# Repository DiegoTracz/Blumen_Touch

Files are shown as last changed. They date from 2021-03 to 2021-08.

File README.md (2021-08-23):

# Interruptor inteligente customizável
O projeto Blumen Touch, é uma solução IoT baseada no ESP8266 com o objetivo de popularizar sistemas de automação residencial de baixo custo.
<h2><b>Introdução</b></h2>
Blumen Touch é um interruptor wi-fi baseado no ESP8266 suportando até 3 botões e 3 relés de estado sólido que suportam 2A cada, 
permitindo controlar até 3 circuitos de iluminação independentes. O Blumen touch foi desenvolvido para ser instalado em caixinhas
4x2, padrão brasileiro, substituindo assim o interruptor padrão que esteja instalado. O controle pode ser feito via comando de voz, via web, smartphone ou manualmente pelos botões.
Além disso possui um interface customizável, onde é possivel colocar qualquer imagem ou foto e customizar como quiser.
<h2><b>Diagrama de fiação </b></h2>
<u1>
  <li> Ligação dos fio para os modelos B1, B2 e B3 </li>
  
  <li> Tutorial instalação:  https://youtu.be/j6668FpMcGA </li>
  <u1>
   <h2>

<h2><b>Bibliotecas necessárias</b></h2>

|  <b>Nome</b> |  <b>Link</b> |
|---|---|
| ArduinoJson  |<a href="https://github.com/bblanchon/ArduinoJson/">GIT</a>  | 
|  WebSockets | <a href="https://github.com/Links2004/arduinoWebSockets/">GIT</a>  |  
| Sirincpro  |  <a href="https://github.com/sinricpro/esp8266-esp32-sdk/">GIT</a> | 
| WifiManager  |<a href="https://github.com/tzapu/WiFiManager/">GIT</a> | 

<h2><b>Hardware</b></h2>
<u1>
  <li> Blumen Touch Placa 1, 2 e 3 teclas frente e trás</li>
  
  
  
  <u1>
   <h2><b>Suporte para placa</b></h2
     
 <u1>
  <li> Suporte (PLA) e espelho (acrilico) </li>
     

 <u1>
   <h2><b>Esquemáticos</b></h2>
     
<u1>
  <li> Esquematico frente </li>
  
  <li> Esquematico trás </li>
   
  
  <u1>
   
  <h2><b>GPIO's</b></h2>

|  <b>GPIO</b> |  <b>PINO</b> |
|---|---|
|16  | BOTÃO 1  | 
|  14 | BOTÃO 2  |  
| 12  |  BOTÃO 3|
| 05  |  RELÉ 1| 
| 04  |  RELÉ 2| 
| 02  |  RELÉ 3| 

  <h2><b>Software necessário</b></h2>
 <li><b>Sirinc Pro</b>: O Sirinc Pro é um serviço de nuvem para dispositivos inteligentes, onde de forma gratuita podemos hospedar até 3 dispositivos gratuitamente e a partir dele fazer o acionamento dos interruptores pelo aplicativo ou comando de voz.</li>
  <li> <b> Passo a passo configuração da placa utilizando a plataforma do Sinric Pro<b>: https://youtu.be/px-q5iuD3NI</li>

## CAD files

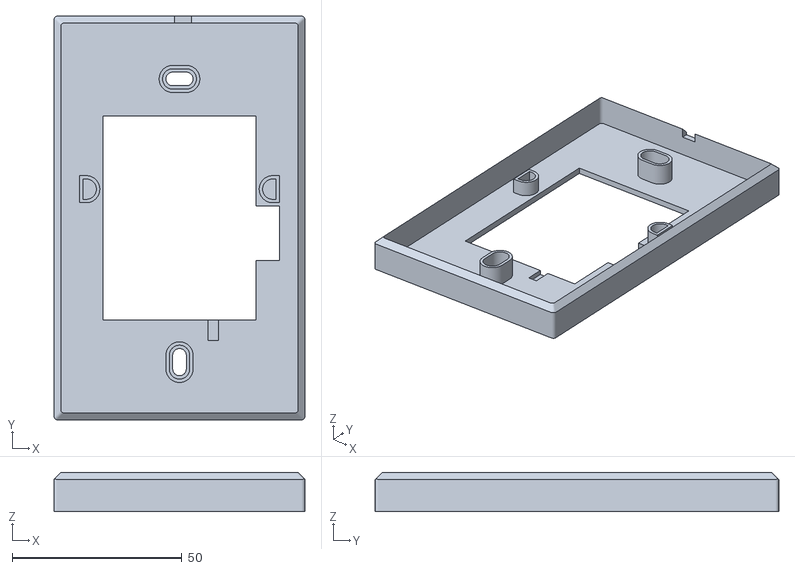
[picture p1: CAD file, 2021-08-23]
Impressão 3d/SuporteInterruptor.stl
74.0 x 119.0 x 11.6

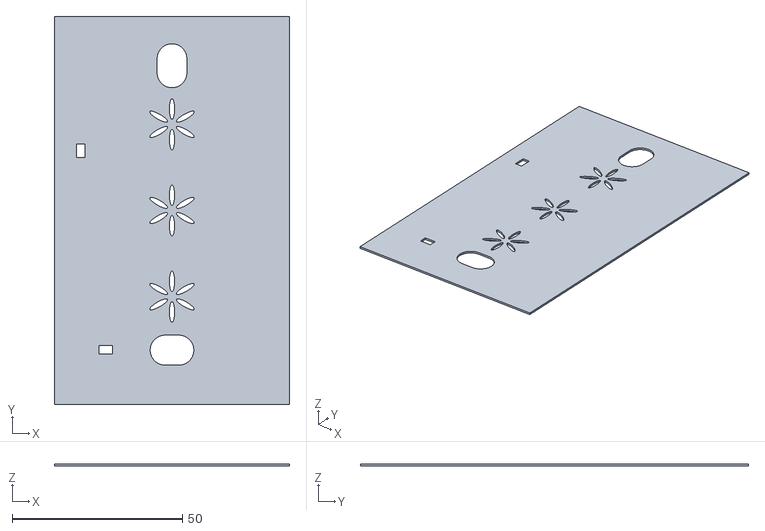
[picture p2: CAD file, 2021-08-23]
Impressão 3d/Proteção placa.stl
69.0 x 114.0 x 0.6

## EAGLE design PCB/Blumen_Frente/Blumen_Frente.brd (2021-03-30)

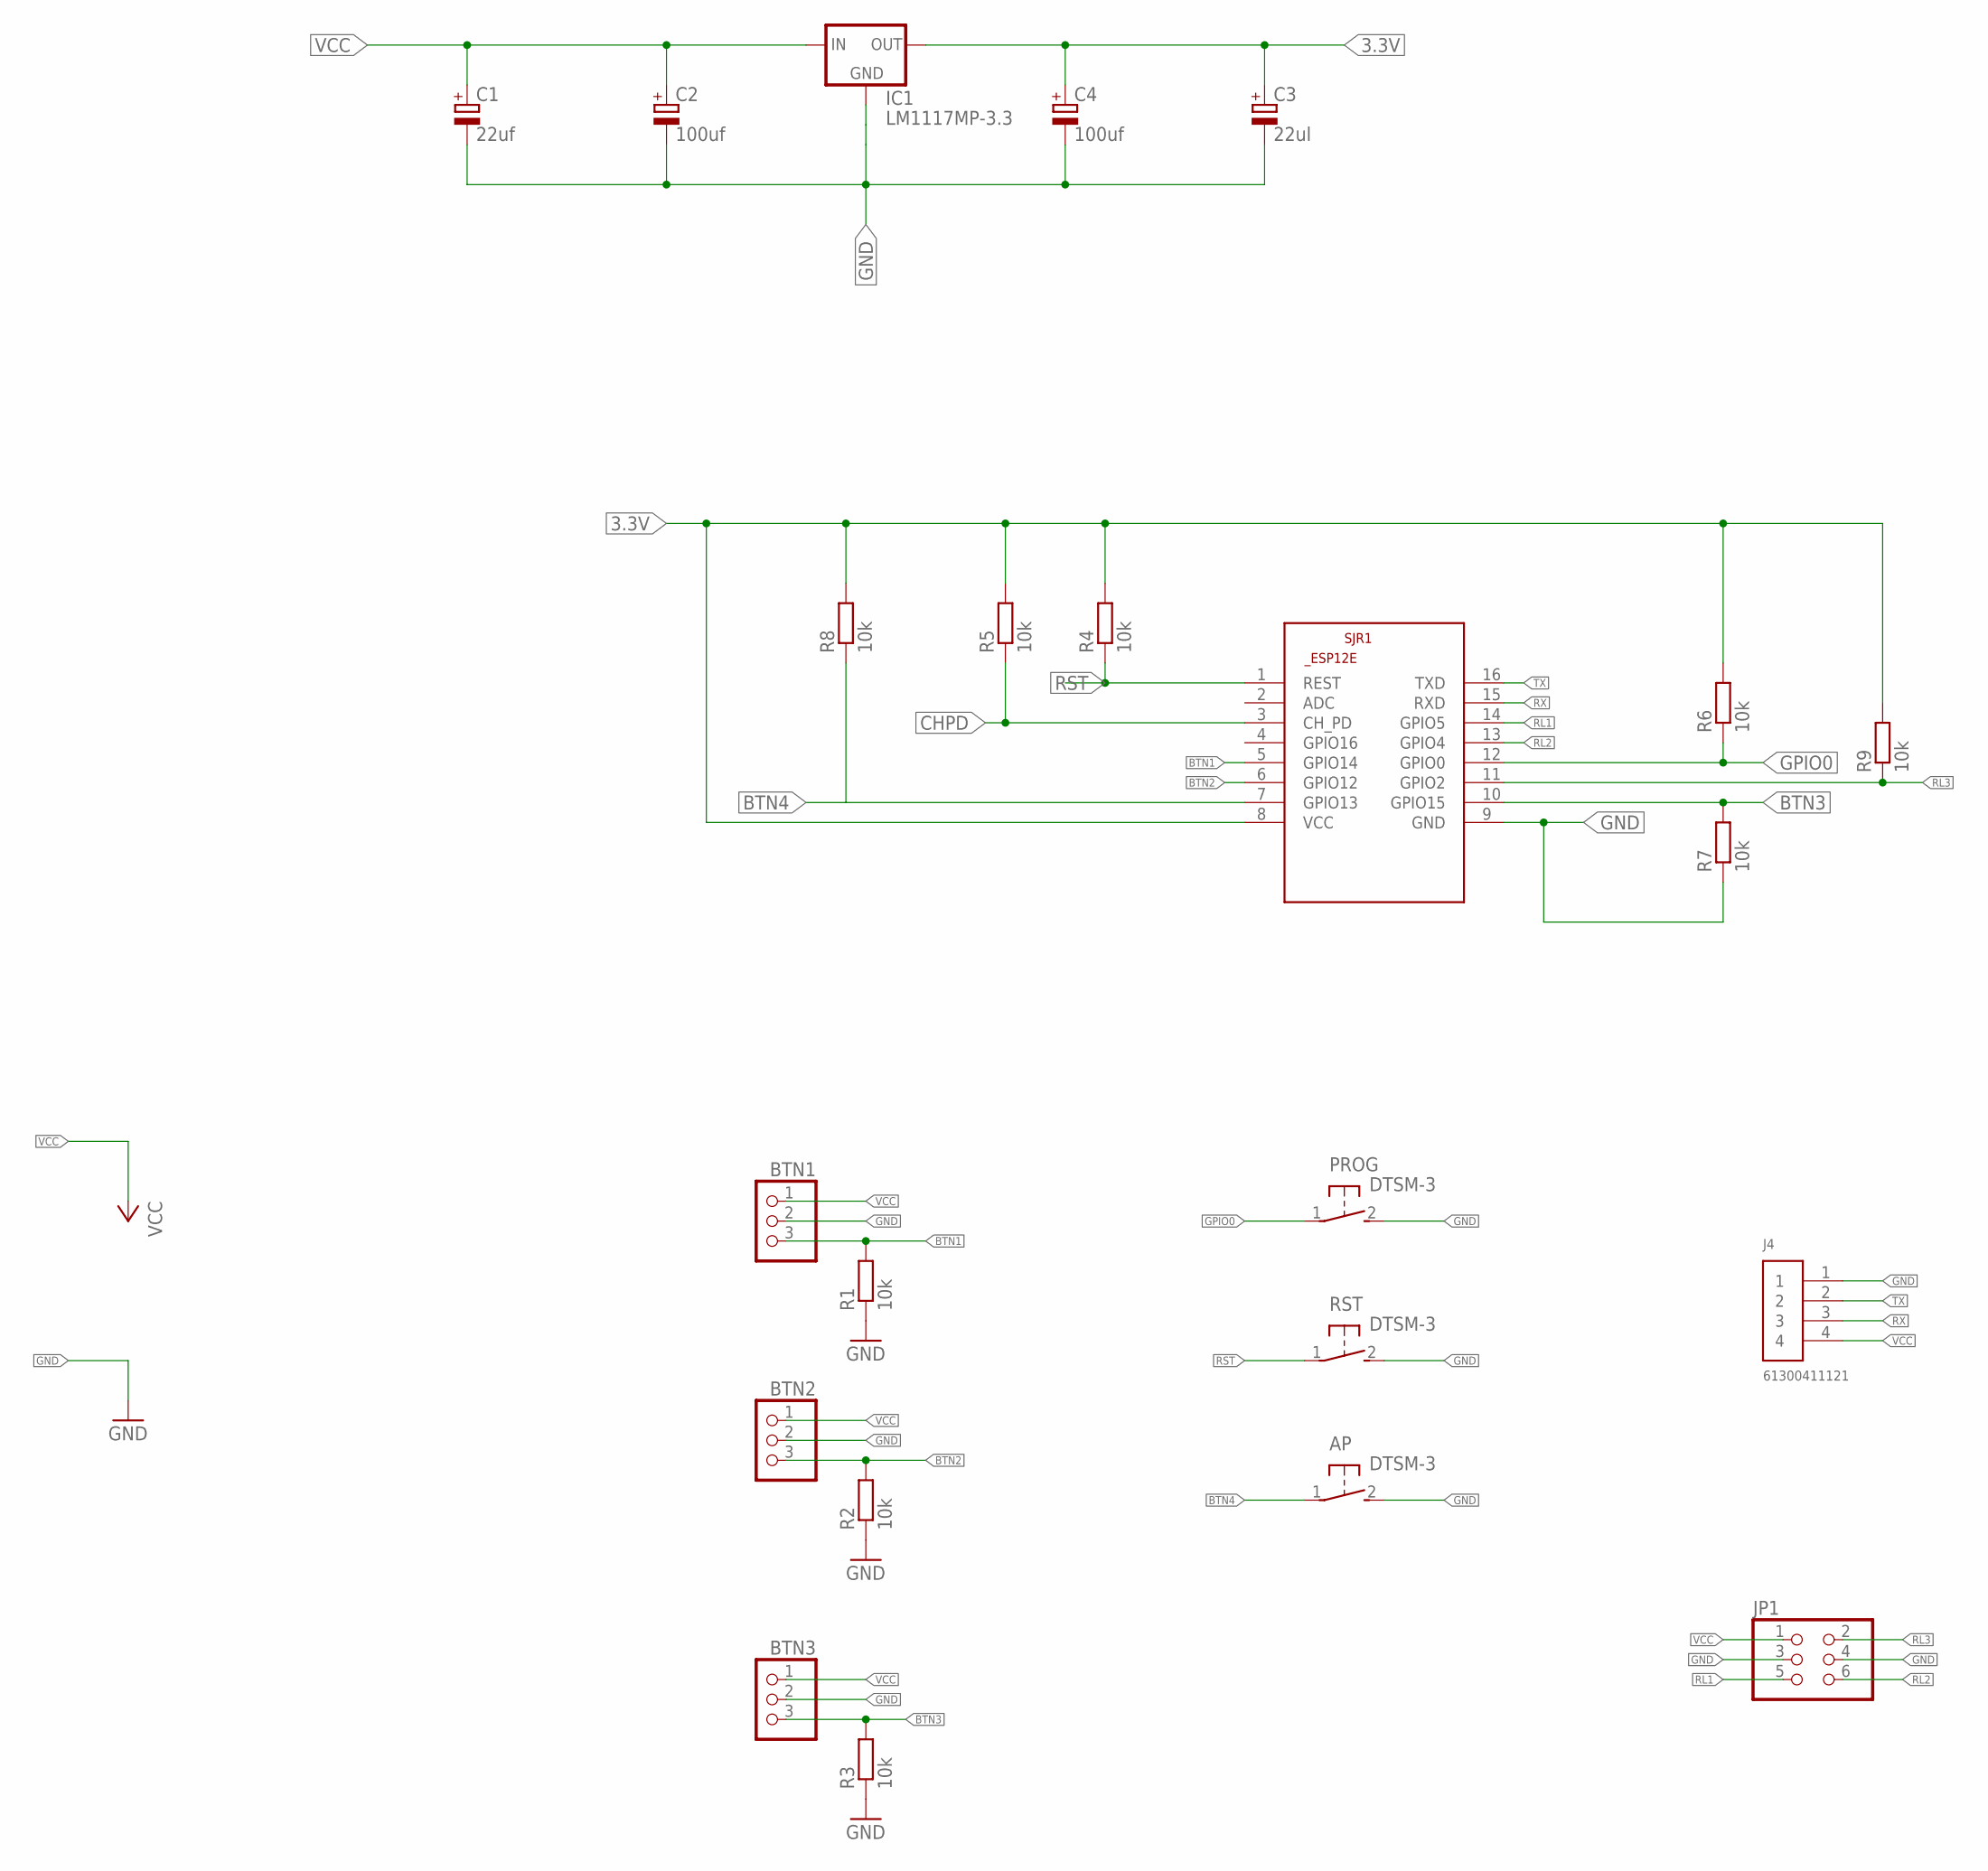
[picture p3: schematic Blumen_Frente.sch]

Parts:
AP: DTSM-3
BTN1, BTN2, BTN3: PINHD-1X3; 1X03
C1: 22uf; 153CLV-0505
C2, C4: 100uf; 153CLV-0605
C3: 22ul; 153CLV-0505
IC1: LM1117MP-3.3; SOT223
J4: 61300411121
JP1: PINHD-2X3; 2X03
PROG: DTSM-3
R1, R2, R3, R4, R5, R6, R7, R8, R9: 10k; R0805
RST: DTSM-3
SJR1: ESP8266-12EESP12E; ESP8266-ESP12E

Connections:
3.3V: C3.+, C4.+, IC1.2 (OUT), IC1.4 (OUT), R4.2, R5.2, R6.2, R8.2, R9.2, SJR1.8 (VCC)
BTN1: BTN1.3, R1.2, SJR1.5 (GPIO14)
BTN2: BTN2.3, R2.2, SJR1.6 (GPIO12)
BTN3: BTN3.3, R3.2, R7.2, SJR1.10 (GPIO15)
BTN4: AP.1, R8.1, SJR1.7 (GPIO13)
CHPD: R5.1, SJR1.3 (CH_PD)
GND: AP.2, BTN1.2, BTN2.2, BTN3.2, C1.-, C2.-, C3.-, C4.-, IC1.1 (GND), J4.1, JP1.3, JP1.4, PROG.2, R1.1, R2.1, R3.1, R7.1, RST.2, SJR1.9 (GND)
GPIO0: PROG.1, R6.1, SJR1.12 (GPIO0)
RL1: JP1.5, SJR1.14 (GPIO5)
RL2: JP1.6, SJR1.13 (GPIO4)
RL3: JP1.2, R9.1, SJR1.11 (GPIO2)
RST: R4.1, RST.1, SJR1.1 (REST)
RX: J4.3, SJR1.15 (RXD)
TX: J4.2, SJR1.16 (TXD)
VCC: BTN1.1, BTN2.1, BTN3.1, C1.+, C2.+, IC1.3 (IN), J4.4, JP1.1

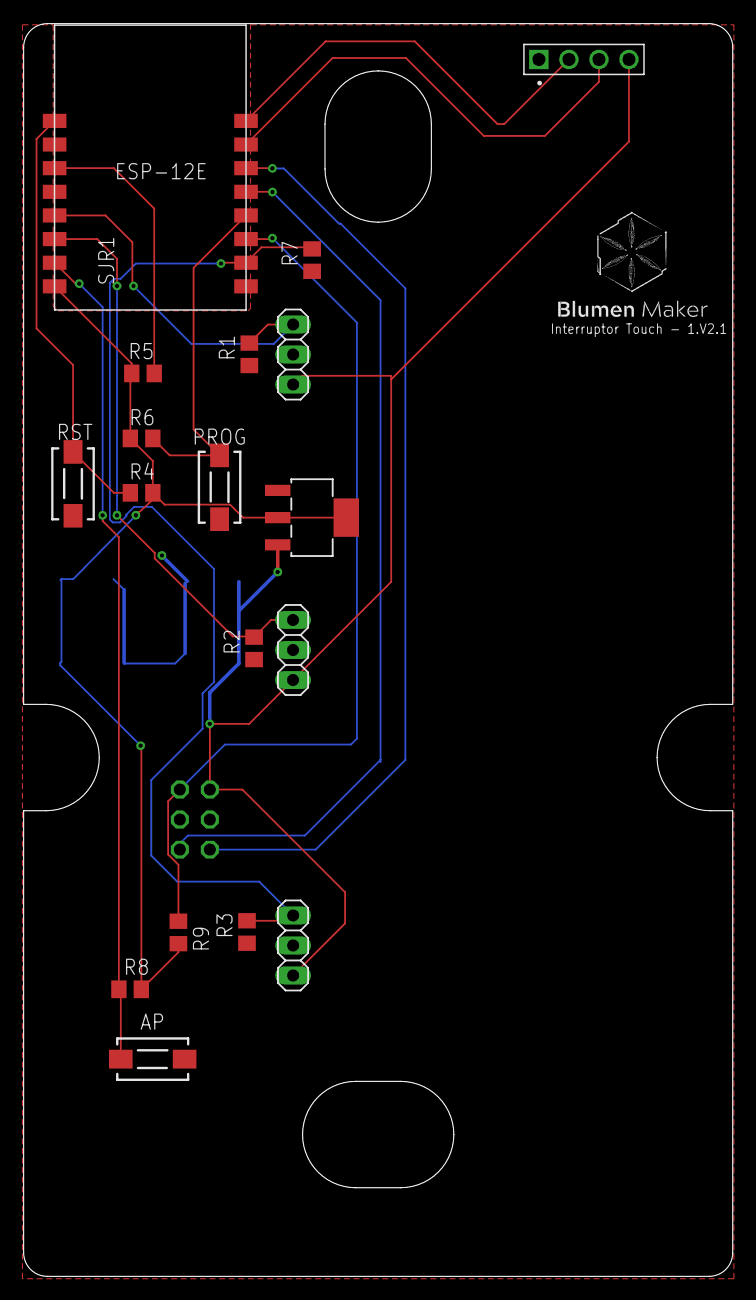
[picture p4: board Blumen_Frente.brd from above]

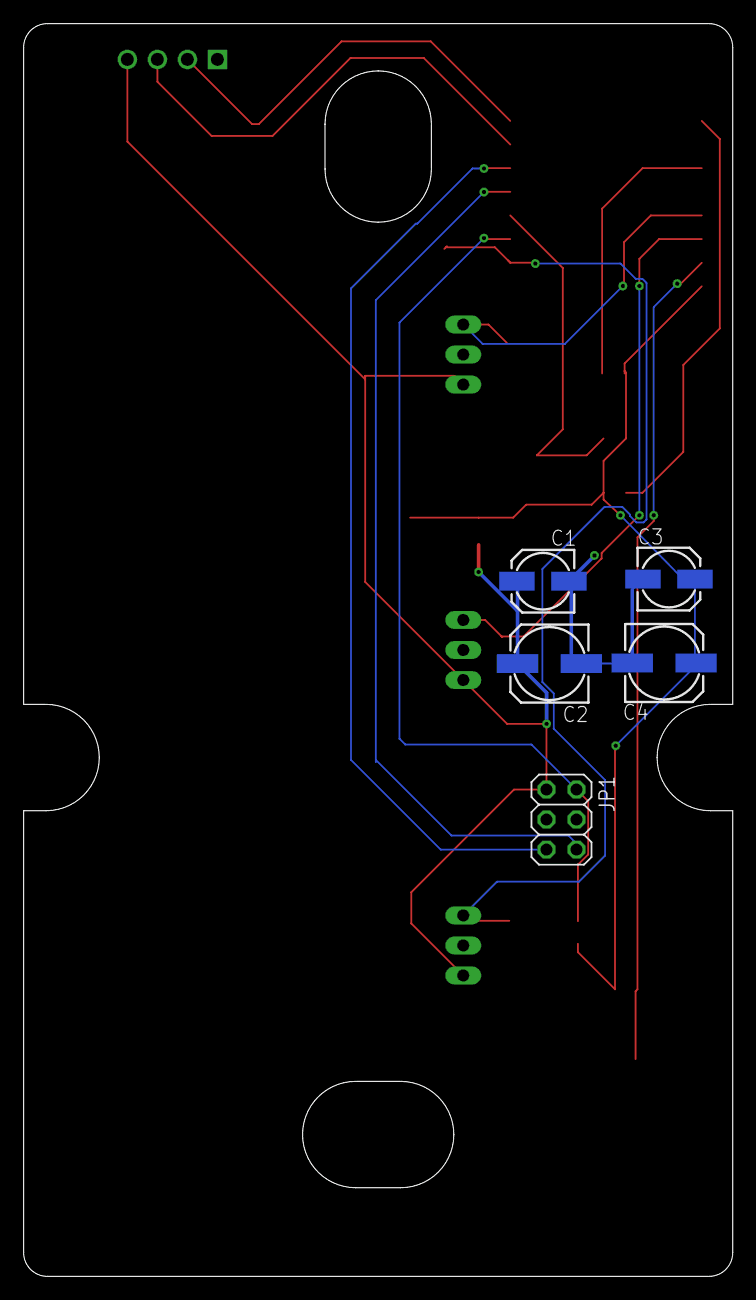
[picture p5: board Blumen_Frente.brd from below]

Board: 2 copper layers, 60.0 x 106.0 mm, 23 parts (5 on the bottom side), 15 nets.

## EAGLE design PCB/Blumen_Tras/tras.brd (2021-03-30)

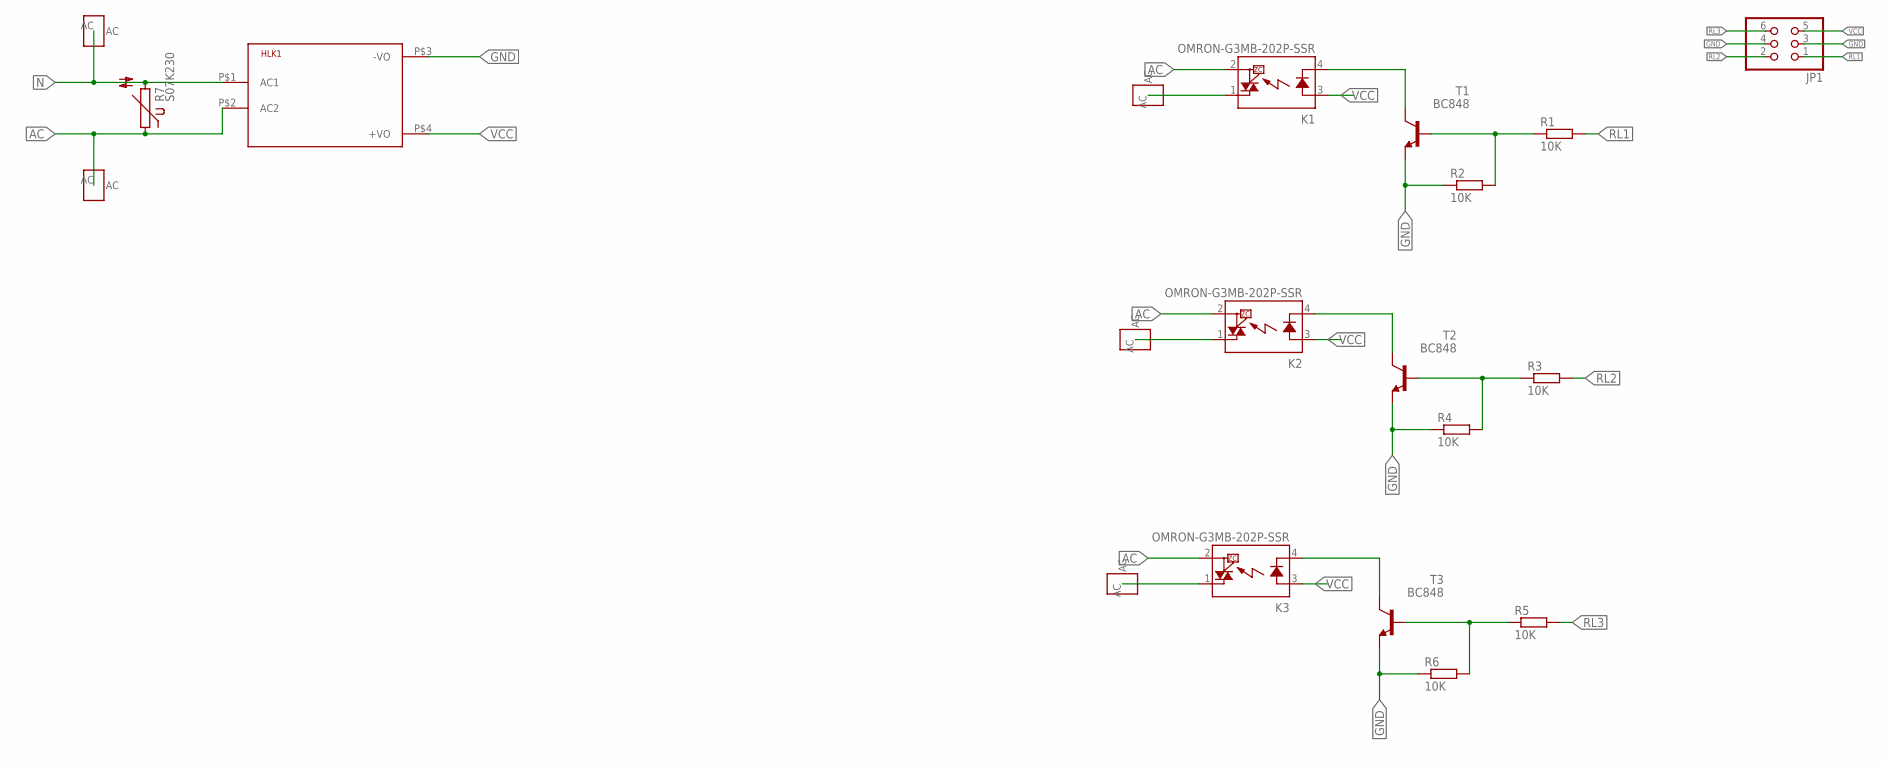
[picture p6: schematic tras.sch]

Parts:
AC: PAN_AC; PAD_AC
HLK1: HLK-PM013W; HLK-PM01
JP1: PINHD-2X3M; 2X03M
K1, K2, K3: OMRON-G3MB-202P-SSR
L1, L2, L3: PAN_AC; PAD_AC
N: PAN_AC; PAD_AC
R1, R2, R3, R4, R5, R6: 10K; R0805
R7: S07K230
T1, T2, T3: BC848; SOT23

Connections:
AC: AC.AC, HLK1.P$2 (AC2), K1.2 (DS2), K2.2 (DS2), K3.2 (DS2), R7.1
GND: HLK1.P$3 (-VO), JP1.3, JP1.4, R2.1, R4.1, R6.1, T1.2 (E), T2.2 (E), T3.2 (E)
L1: K1.1 (DS1), L1.AC
L2: K2.1 (DS1), L2.AC
L3: K3.1 (DS1), L3.AC
N: HLK1.P$1 (AC1), N.AC, R7.2
unnamed: K1.4 (K), T1.3 (C)
unnamed: R1.1, R2.2, T1.1 (B)
unnamed: K2.4 (K), T2.3 (C)
unnamed: R3.1, R4.2, T2.1 (B)
unnamed: K3.4 (K), T3.3 (C)
unnamed: R5.1, R6.2, T3.1 (B)
RL1: JP1.1, R1.2
RL2: JP1.2, R3.2
RL3: JP1.6, R5.2
VCC: HLK1.P$4 (+VO), JP1.5, K1.3 (A), K2.3 (A), K3.3 (A)

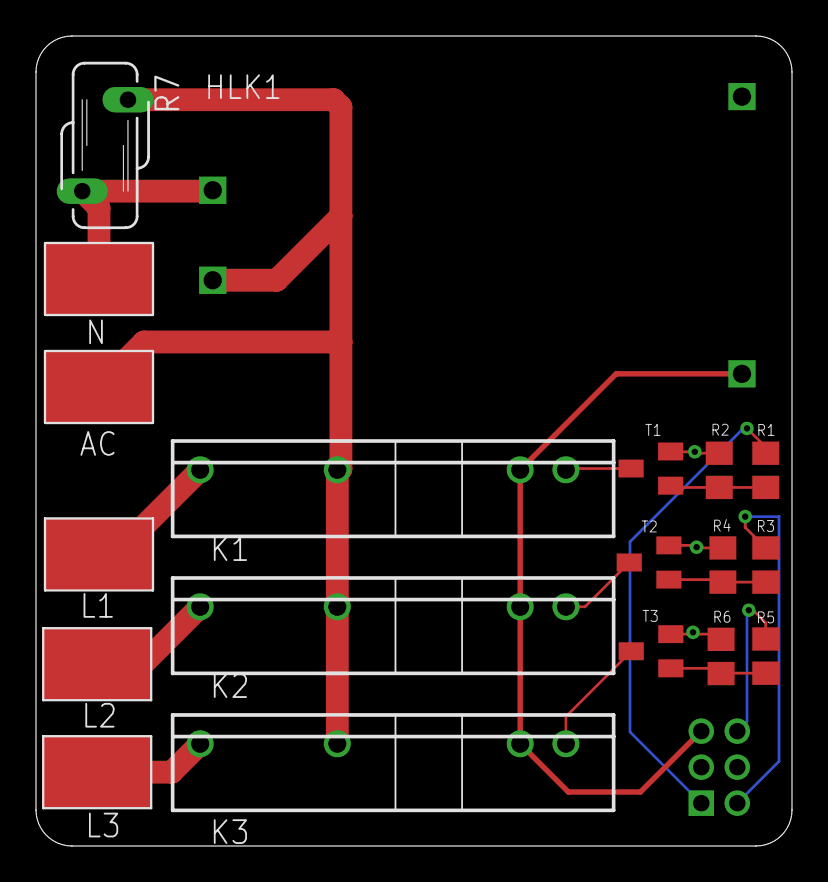
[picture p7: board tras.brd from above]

Board: 2 copper layers, 42.0 x 45.0 mm, 20 parts (1 on the bottom side), 16 nets.

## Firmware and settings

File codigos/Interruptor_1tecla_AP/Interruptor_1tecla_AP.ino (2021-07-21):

 /*
   ADVANCED example for: how to use up to N SinricPro Switch devices on one ESP module
                         to control N relays and N flipSwitches for manually control:
   - setup N SinricPro switch devices
   - setup N relays
   - setup N flipSwitches to control relays manually
     (flipSwitch can be a tactile button or a toggle switch and is setup in line #52)

   - handle request using just one callback to switch relay
   - handle flipSwitches to switch relays manually and send event to sinricPro server

   - SinricPro deviceId and PIN configuration for relays and buttins is done in std::map<String, deviceConfig_t> devices

   If you encounter any issues:
   - check the readme.md at https://github.com/sinricpro/esp8266-esp32-sdk/blob/master/README.md
   - ensure all dependent libraries are installed
     - see https://github.com/sinricpro/esp8266-esp32-sdk/blob/master/README.md#arduinoide
     - see https://github.com/sinricpro/esp8266-esp32-sdk/blob/master/README.md#dependencies
   - open serial monitor and check whats happening
   - check full user documentation at https://sinricpro.github.io/esp8266-esp32-sdk
   - visit https://github.com/sinricpro/esp8266-esp32-sdk/issues and check for existing issues or open a new one
*/

// Uncomment the following line to enable serial debug output
//#define ENABLE_DEBUG

#ifdef ENABLE_DEBUG
#define DEBUG_ESP_PORT Serial
#define NODEBUG_WEBSOCKETS
#define NDEBUG
#endif

#include <Arduino.h>
#ifdef ESP8266
#include <ESP8266WiFi.h>
#endif
#ifdef ESP32
#include <WiFi.h>
#endif

#include <WiFiManager.h>//https://github.com/tzapu/WiFiManager

#include "SinricPro.h"
#include "SinricProSwitch.h"

#include <map>

#include <DNSServer.h>
#include <ESP8266WebServer.h>

#define APP_KEY           "cole aqui o app_key"      // Should look like "de0bxxxx-1x3x-4x3x-ax2x-5dabxxxxxxxx"
#define APP_SECRET        "cole aqui o app_secret"  // Should look like "5f36xxxx-x3x7-4x3x-xexe-e86724a9xxxx-4c4axxxx-3x3x-x5xe-x9x3-333d65xxxxxx"

// comment the following line if you use a toggle switches instead of tactile buttons
#include <FS.h>
#define BAUD_RATE   9600

#define DEBOUNCE_TIME 250

#define AP_PIN  13

typedef struct {      // struct for the std::map below
  int relayPIN;
  int flipSwitchPIN;
} deviceConfig_t;


// this is the main configuration
// please put in your deviceId, the PIN for Relay and PIN for flipSwitch
// this can be up to N devices...depending on how much pin's available on your device ;)
// right now we have 4 devicesIds going to 4 relays and 4 flip switches to switch the relay manually
std::map<String, deviceConfig_t> devices = {
  //{deviceId, {relayPIN,  flipSwitchPIN}}
  {"cole aqui o id do device 1", {  5, 14 }}
};

typedef struct {      // struct for the std::map below
  String deviceId;
  bool lastFlipSwitchState;
  unsigned long lastFlipSwitchChange;
} flipSwitchConfig_t;

std::map<int, flipSwitchConfig_t> flipSwitches;    // this map is used to map flipSwitch PINs to deviceId and handling debounce and last flipSwitch state checks
// it will be setup in "setupFlipSwitches" function, using informations from devices map

void setupRelays() {
  for (auto &device : devices) {           // for each device (relay, flipSwitch combination)
    int relayPIN = device.second.relayPIN; // get the relay pin
    pinMode(relayPIN, OUTPUT);             // set relay pin to OUTPUT
  }
}

void setupFlipSwitches() {
  for (auto &device : devices)  {                     // for each device (relay / flipSwitch combination)
    flipSwitchConfig_t flipSwitchConfig;              // create a new flipSwitch configuration

    flipSwitchConfig.deviceId = device.first;         // set the deviceId
    flipSwitchConfig.lastFlipSwitchChange = 0;        // set debounce time
    flipSwitchConfig.lastFlipSwitchState = false;     // set lastFlipSwitchState to false (LOW)

    int flipSwitchPIN = device.second.flipSwitchPIN;  // get the flipSwitchPIN

    flipSwitches[flipSwitchPIN] = flipSwitchConfig;   // save the flipSwitch config to flipSwitches map
    pinMode(flipSwitchPIN, INPUT);                   // set the flipSwitch pin to INPUT
  }
}

bool onPowerState(String deviceId, bool &state)
{
  Serial.printf("%s: %s\r\n", deviceId.c_str(), state ? "on" : "off");
  int relayPIN = devices[deviceId].relayPIN; // get the relay pin for corresponding device
  digitalWrite(relayPIN, state);             // set the new relay state
  return true;
}

void handleFlipSwitches() {
  unsigned long actualMillis = millis();                                          // get actual millis
  for (auto &flipSwitch : flipSwitches) {                                         // for each flipSwitch in flipSwitches map
    unsigned long lastFlipSwitchChange = flipSwitch.second.lastFlipSwitchChange;  // get the timestamp when flipSwitch was pressed last time (used to debounce / limit events)

    if (actualMillis - lastFlipSwitchChange > DEBOUNCE_TIME) {                    // if time is > debounce time...

      int flipSwitchPIN = flipSwitch.first;                                       // get the flipSwitch pin from configuration
      bool lastFlipSwitchState = flipSwitch.second.lastFlipSwitchState;           // get the lastFlipSwitchState
      bool flipSwitchState = digitalRead(flipSwitchPIN);                          // read the current flipSwitch state
      if (flipSwitchState != lastFlipSwitchState) {                               // if the flipSwitchState has changed...
#ifdef TACTILE_BUTTON
        if (flipSwitchState) {                                                    // if the tactile button is pressed
#endif
          flipSwitch.second.lastFlipSwitchChange = actualMillis;                  // update lastFlipSwitchChange time
          String deviceId = flipSwitch.second.deviceId;                           // get the deviceId from config
          int relayPIN = devices[deviceId].relayPIN;                              // get the relayPIN from config
          bool newRelayState = !digitalRead(relayPIN);                            // set the new relay State
          digitalWrite(relayPIN, newRelayState);                                  // set the trelay to the new state

          SinricProSwitch &mySwitch = SinricPro[deviceId];                        // get Switch device from SinricPro
          mySwitch.sendPowerStateEvent(newRelayState);                            // send the event
#ifdef TACTILE_BUTTON
        }
#endif
        flipSwitch.second.lastFlipSwitchState = flipSwitchState;                  // update lastFlipSwitchState
      }
    }
  }
}

void setupWiFi()
{

  WiFiManager wifiManager;
  wifiManager.setBreakAfterConfig(true);
  // wifiManager.resetSettings();
  wifiManager.setTimeout(180);
  wifiManager.autoConnect("AP-INTERRUPTOR");
}

void setupSinricPro()
{
  for (auto &device : devices)
  {
    const char *deviceId = device.first.c_str();
    SinricProSwitch &mySwitch = SinricPro[deviceId];
    mySwitch.onPowerState(onPowerState);
  }

  SinricPro.begin(APP_KEY, APP_SECRET);
  SinricPro.restoreDeviceStates(true);
}

void setup()
{

  pinMode(AP_PIN, INPUT);
  Serial.begin(BAUD_RATE);
  setupRelays();
  setupFlipSwitches();
  setupWiFi();
  setupSinricPro();
}

void loop()
{

  SinricPro.handle();
  handleFlipSwitches();
  if ( digitalRead(AP_PIN) == LOW ) {
    WiFiManager wifiManager;
    Serial.println("resetar"); //tenta abrir o portal
    if (!wifiManager.startConfigPortal("AP-INTERRUPTOR") ) {
      Serial.println("Falha ao conectar");
      delay(2000);
      ESP.restart();
      delay(1000);
    }
    Serial.println("Conectou ESP_AP!!!");
  }

}
